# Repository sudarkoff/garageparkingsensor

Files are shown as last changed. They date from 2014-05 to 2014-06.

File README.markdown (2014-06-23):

# Parking Sensor

Garage Parking Sensor is a gizmo that helps you park your car the perfect distance from the wall every time. It can also optionally serve as a presence sensor.

<a href="https://www.flickr.com/photos/sudarkoff/14485954765" title="Garage parking sensor/assistant by George Sudarkoff, on Flickr">Garage parking sensor/assistant</a>

## Usage

To save the sweet spot, using whatever means necessary - your spouse, a tennis ball suspended from the ceiling, a bunch of mirrors with lasers - park the car the disared distance away from the wall where the sensor is mounted (for best results, aim the sensor at your car's bumper). Once satisfied with the location of your car, push the Save button on the gizmo taking care not to interfere with the ultrasound beam between the sensor and the car. The distance will be saved into the non-volatile memory (meaning, it will survive the reboot or the loss of power).

To park in the same perfect spot, drive *slowly* until the red LED starts to blink, then stop. The LEDs of the gizmo indicate the relative distance to your perfect spot. The first three yellow LEDs cover the range from approximately 3 meters (max detectable distance) to within about 20% of the target spot. Two green LEDs are for the 20% to 5% range. Finally, the red LED indicates that you're less than 5% away from your target spot (we're talking millimeters at this point). In practical terms, the sensor forces you to slow down fast and puts you within your target zone with the precision of a sharp shooter. It is *very* accurate!

## Schematics

The circuit is Arduino-compatible. That means it uses the ATmega microprocessor unit with the Arduino bootloader. However, there is no USB on board, the only way to communicate with the board is to use an FTDI breakout board similar to [this](https://www.sparkfun.com/products/9716). The ultrasound sensor used ("PING)))") is probably the most expensive component of this gizmo (I bought mine for about $30). I used [Eagle](http://www.cadsoftusa.com/) to design and draw the schematics and the PCB.

## Firmware

Firmware is Arduino-based, so you'll have to install and know how to use the Arduino software in order to tinker and upload the firmware to the board.

To be continued...

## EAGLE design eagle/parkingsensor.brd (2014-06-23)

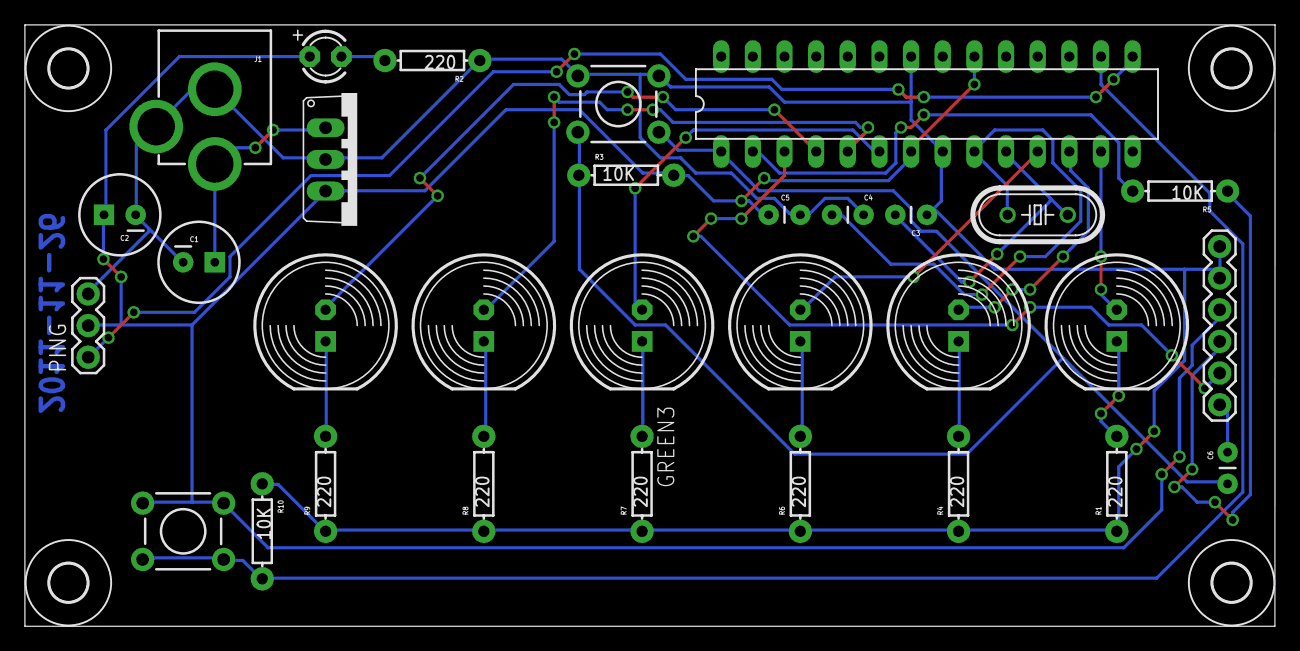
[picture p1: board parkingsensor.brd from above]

Board: 2 copper layers, 100.3 x 48.3 mm, 35 parts (0 on the bottom side), 25 nets.

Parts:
C1: 100uF/25V; CPOL-RADIAL-100UF-25V
C2: 10uF/10V; CPOL-RADIAL-100UF-25V
C3, C4: 22pF; CAP-PTH-SMALL
C5, C6: 0.1uF; CAP-PTH-SMALL
GREEN1, GREEN2, GREEN3: LED10MM
IC1: 7805TV; TO220V
J1: POWER_JACKPTH; POWER_JACK_PTH
JP1: XBee/Program; 1X06
LED1: POWER; LED3MM
PING: 1X03
Q1: 16MHz; HC49/S
R1, R2, R4, R6, R7, R8, R9: 220; AXIAL-0.3
R3, R5, R10: 10K; AXIAL-0.3
RED1: LED10MM
RESET: TACTILE-PTH
STORE: TACTILE-PTH
U$1, U$2, U$3, U$4: MOUNTINGHOLE_3.0
YELLOW1, YELLOW2: LED10MM
ZIC1: ATMEGA328; DIL28-3

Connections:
+5V: C2.1, C5.2, IC1.3, JP1.4, LED1.A, PING.2, R3.P$2, STORE.3, STORE.4, ZIC1.7, ZIC1.20
+12V: C1.1, IC1.1, J1.PWR
DIST: PING.1, ZIC1.15
DTR: C6.1, JP1.1
GND: C1.2, C2.2, C3.1, C4.1, C5.1, IC1.2, J1.GND, J1.GNDBREAK, JP1.5, JP1.6, PING.3, R1.P$1, R2.P$1, R4.P$1, R6.P$1, R7.P$1, R8.P$1, R9.P$1, R10.P$1, RESET.1, RESET.2, ZIC1.8, ZIC1.22
GREEN1: GREEN1.A, ZIC1.4
GREEN2: GREEN2.A, ZIC1.5
GREEN3: GREEN3.A, ZIC1.6
unnamed: R1.P$2, RED1.K
unnamed: R4.P$2, YELLOW2.K
unnamed: R6.P$2, YELLOW1.K
unnamed: GREEN3.K, R7.P$2
unnamed: C3.2, Q1.2, ZIC1.10
unnamed: LED1.K, R2.P$2
unnamed: C4.2, Q1.1, ZIC1.9
unnamed: C6.2, R3.P$1, RESET.3, RESET.4, ZIC1.1
unnamed: JP1.3, R5.P$1
unnamed: GREEN2.K, R8.P$2
unnamed: GREEN1.K, R9.P$2
unnamed: R10.P$2, STORE.1, STORE.2, ZIC1.16
RED1: RED1.A, ZIC1.13
RX: R5.P$2, ZIC1.2
TX: JP1.2, ZIC1.3
YELLOW1: YELLOW1.A, ZIC1.11
YELLOW2: YELLOW2.A, ZIC1.12

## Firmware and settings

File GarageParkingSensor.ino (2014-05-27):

/**
 * Garage Parking Sensor
 */

#include <avr/sleep.h>
#include <avr/wdt.h>

#include <Bounce.h>
#include <EEPROM.h>

// Arduino convenience functions.
// https://github.com/sudarkoff/hardwin
#define USE_EEPROM
#include <hardwin.h>

// Uncomment to enable debug output to serial
//#define DEBUG

#define NUM_READS 1                // PING))) is accurate enough, no need for averaging
#define USEC_PER_CM 29             // microseconds per centimeter
#define EPSILON (USEC_PER_CM * 10) // If motion is less than 10 cm, we ignore it
#define SLEEP_WAITING_PERIOD 3000  // Period of inactivity before ATmega goes to sleep
#define SAVE_WAITING_PERIOD 5000   // To prevent frequent writes to EEPROM (like saving distance)

const int pingPin = 9;             // The pin PING))) sensor is connected to
const int savePin = 10;            // The pin Save button is connected to

const int distanceLed[] = {2, 3, 4, 5, 6, 7};
                                   // Pins for LEDs of proximity indicator
const int distanceLimitAddr = 0;   // EEPROM address of the distance threshold parameter
long distanceLimit;                // Local instance of the distance threshold parameter (cm)
long distanceMax = 300;            // 300 cm is the maximum distance PING))) can detect

// De-bouncer for Save button
Bounce saveButton = Bounce(savePin, 5);

// Global flag for ATmega Watchdog
volatile boolean f_wdt = 1;

/**
 * Arduino setup routine.
 */

void
setup()
{
  // Initialize proximity indicator pins
  for (int i=0; i<6; ++i) {
    pinMode(distanceLed[i], OUTPUT);
  }

  // Initialize Save button pin
  pinMode(savePin, INPUT);
  // Read the distance threshold value from EEPROM (default is 20 cm)
  hardwin::EEPROM_read(distanceLimitAddr, distanceLimit,
    static_cast<long>(3), static_cast<long>(300), static_cast<long>(20));

  // CPU Sleep Modes 
  // SM2 SM1 SM0 Sleep Mode
  // 0    0  0 Idle
  // 0    0  1 ADC Noise Reduction
  // 0    1  0 Power-down
  // 0    1  1 Power-save
  // 1    0  0 Reserved
  // 1    0  1 Reserved
  // 1    1  0 Standby(1)
  cbi( SMCR,SE );      // sleep enable, power down mode
  cbi( SMCR,SM0 );     // power down mode
  sbi( SMCR,SM1 );     // power down mode
  cbi( SMCR,SM2 );     // power down mode

  // Watchdog timer: 2 seconds appears to be responsive enough
  setup_watchdog(7);
  
#ifdef DEBUG
  Serial.begin(9600);
#endif
}

/**
 * Main loop
 */

void
loop()
{
  static long prevDuration = 0;
  static long prevDurationAt = 0;
  static long lastSaved = 0;
  static boolean sleep_mode = false;

  // Read the sensor NUM_READS times and take the average discarding outliers
  long duration = readDuration(NUM_READS);

  // Convert duration to distance
  long cm = usec2cm(duration);

  // If the distance changed by more than EPSILON ...
  if (!hardwin::equal(duration, prevDuration, EPSILON)) {
    // Note the last change
    sleep_mode = false;
    prevDuration = duration;
    prevDurationAt = millis();
  } else {
    // Otherwise, if there was no change for at least SLEEP_WAITING_PERIOD microseconds
    if (abs(millis() - prevDurationAt) > SLEEP_WAITING_PERIOD) {
      // go to sleep
      sleep_mode = true;
      sleep();
    }
  }

  // If there was change in distance (car is moving)
  if (!sleep_mode) {
    // Update the proximity indicator
    updateProximity(cm);
  }

  // If the Save button is pushed
  saveButton.update();
  if (saveButton.read() == HIGH) {
    // And we didn't save the distance threshold in the last SAVE_WAITING_PERIOD microseconds
    if (millis() - lastSaved > SAVE_WAITING_PERIOD) {
      // save the new distance threshold
      hardwin::EEPROM_write(distanceLimitAddr, cm);
      distanceLimit = cm;
      lastSaved = millis();

      // and flash the RED LED 3 times as a confirmation
      int states[] = {LOW, LOW, LOW, LOW, LOW, LOW};        // OFF
      switchLeds(states);
      hardwin::flashLed(distanceLed[5], 3, 50);
    }
  }

  delay(75);
}

/**
 * Read PING))) sensor
 *
 * Result:
 *   time it took the sound to travel to the target and back in microseconts
 */

long
readPing()
{
  // The PING))) is triggered by a HIGH pulse of 2 or more microseconds.
  // Give a short LOW pulse beforehand to ensure a clean HIGH pulse:
  pinMode(pingPin, OUTPUT);
  digitalWrite(pingPin, LOW);
  delayMicroseconds(2);
  digitalWrite(pingPin, HIGH);
  delayMicroseconds(5);
  digitalWrite(pingPin, LOW);

  // The same pin is used to read the signal from the PING))): a HIGH
  // pulse whose duration is the time (in microseconds) from the sending
  // of the ping to the reception of its echo off of an object.
  pinMode(pingPin, INPUT);
  long duration = pulseIn(pingPin, HIGH);

  return duration;
}


/**
 * Read PING))) sensor a number of times (up to 10) and return the average while discarding outliers.
 *
 * Note:
 *   I wrote this function trying to combat the "accuracy issue". It turns out the issue was my power
 *   supply that couldn't source enough current to power PING))), so it was producing wrong results.
 *   Replacing the power supply fixed the issue and there's no need to take more than one measurement.
 */

long
readDuration(long times)
{
  long sum = 0;
  static long durationArray[10];

  for (int i = 0; i < times; i++) {
    durationArray[i] = readPing();
#ifdef DEBUG
    Serial.print(durationArray[i]); Serial.print(", ");
#endif
    sum += durationArray[i];
  }
  long mean = sum / times;
#ifdef DEBUG
  Serial.println(mean);
#endif

#if 0
  // Discard outliers using a very simple heuristic:
  //   if a value differs from the mean by more than EPSILON, discard it
  long good_times = times;

  for (int i = 0; i < times; i++) {
    if (abs(durationArray[i] - mean) > EPSILON) {
#ifdef DEBUG
      Serial.print("outlier: "); Serial.println(durationArray[i]);
#endif
      sum -= durationArray[i];
      good_times--;
    } 
  }
  
  mean = sum / good_times;
#endif // 0

  return mean;
}


/**
 * Convert time delay in microseconds it took the sound to travel to the target and back to centimeters.
 */

long
usec2cm(long usec)
{
  // Speed of sound is 340 m/s or 29 usec/cm.
  // The sound travels out and back, so devide the distance by 2.
  return usec / 29 / 2;
}


/**
 * Update the proximity indicator LEDs.
 */
 
void
updateProximity(long distance)
{
  double rangeThreshold[] = {
    distanceMax,
    distanceLimit + (distanceMax - distanceLimit) * 0.65,
    distanceLimit + (distanceMax - distanceLimit) * 0.40,
    distanceLimit + (distanceMax - distanceLimit) * 0.20,
    distanceLimit + (distanceMax - distanceLimit) * 0.05,
    distanceLimit
  };

  if (distance > rangeThreshold[0]) {
    int states[] = {LOW, LOW, LOW, LOW, LOW, LOW};        // OFF
    switchLeds(states);
  }
  else if (distance > rangeThreshold[1]) {
    int states[] = {HIGH, LOW, LOW, LOW, LOW, LOW};       // GREEN1
    switchLeds(states);
  }
  else if (distance > rangeThreshold[2]) {
    int states[] = {HIGH, HIGH, LOW, LOW, LOW, LOW};      // GREEN2
    switchLeds(states);
  }
  else if (distance > rangeThreshold[3]) {
    int states[] = {HIGH, HIGH, HIGH, LOW, LOW, LOW};     // GREEN3
    switchLeds(states);
  }
  else if (distance > rangeThreshold[4]) {
    int states[] = {HIGH, HIGH, HIGH, HIGH, LOW, LOW};    // YELLOW1
    switchLeds(states);
  }
  else if (distance > rangeThreshold[5]) {
    int states[] = {HIGH, HIGH, HIGH, HIGH, HIGH, LOW};   // YELLOW2
    switchLeds(states);
  }
  else {
    int states[] = {HIGH, HIGH, HIGH, HIGH, HIGH, HIGH};  // RED
    switchLeds(states);
  }
}


/**
 * Turn on/off the specified LEDs
 */

void
switchLeds(int state[])
{
  for (int i = 0; i < 5; ++i) {
    digitalWrite(distanceLed[i], state[i]);
  }
  if (state[5] == HIGH) {
    hardwin::flashLed(distanceLed[5], 1, 50);
  } else {
    digitalWrite(distanceLed[5], LOW);
    delay(50);
  }
}


/**
 * Put ATmega to sleep (see setup() for details).
 */

void
sleep()
{
  // Turn off the proximity indicator
  int states[] = {LOW, LOW, LOW, LOW, LOW, LOW};
  switchLeds(states);

  // Switch ADC OFF
  cbi(ADCSRA,ADEN);

  // Put ATmega to sleep
  set_sleep_mode(SLEEP_MODE_PWR_DOWN);
  sleep_enable();
  sleep_mode();

  // zzzzz.....

  // Wake up
  sleep_disable();

  // Switch ADC ON
  sbi(ADCSRA,ADEN);
}


/**
 * Setup the watchdog to wake up ATmega after a specified period of time:
 *
 * 0 = 16 ms
 * 1 = 32 ms
 * 2 = 64 ms
 * 3 = 128 ms
 * 4 = 250 ms
 * 5 = 500 ms
 * 6 = 1 sec
 * 7 = 2 sec
 * 8 = 4 sec
 * 9 = 8 sec
 */

void
setup_watchdog(int ii) {

  byte bb;
  int ww;
  if (ii > 9 ) ii=9;
  bb=ii & 7;
  if (ii > 7) bb|= (1<<5);
  bb|= (1<<WDCE);
  ww=bb;
 
  MCUSR &= ~(1<<WDRF);
  // start timed sequence
  WDTCSR |= (1<<WDCE) | (1<<WDE);
  // set new watchdog timeout value
  WDTCSR = bb;
  WDTCSR |= _BV(WDIE);
}


/**
 * Watchdog Interrupt Service is executed when watchdog timed out
 */

ISR(WDT_vect) {
  f_wdt=1;  // set global flag
}

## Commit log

2014-05-27 Initial version of the Parking Sensor firmware.
2014-06-23 Add the schematic and the PCB layout.
    [parkingsensor.brd, parkingsensor.sch]
